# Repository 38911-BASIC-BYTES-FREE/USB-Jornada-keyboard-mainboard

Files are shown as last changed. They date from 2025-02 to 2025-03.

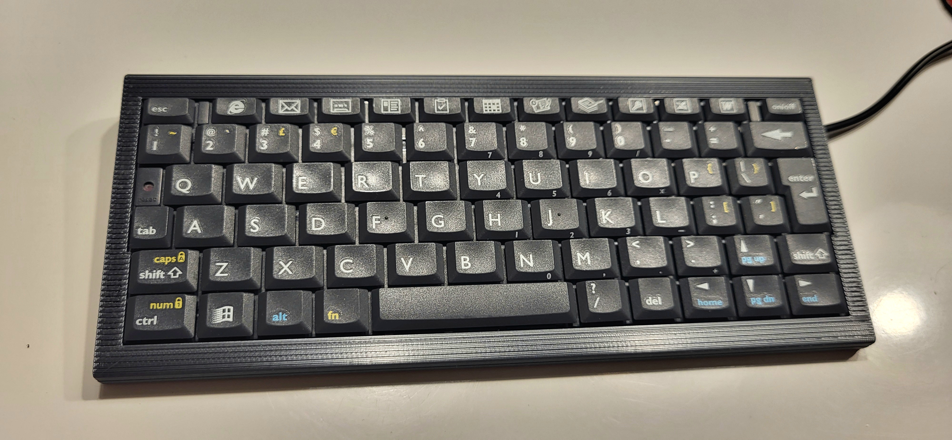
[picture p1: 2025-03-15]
Jornada-Keyboard-Code-FN-english/English_lauout_with_FN.jpg

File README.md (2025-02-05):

Jornada keyboard adapter for using it as a USB HID Keyboard.
Compile it and upload in Arduino choosing Arduino Micro board.
Modification of https://github.com/RasmusB/USB-Keyboard-Adapter .
Used in project https://www.thingiverse.com/thing:6938611 .
PCB project in the folder Jornada_keyboard_mainboard .

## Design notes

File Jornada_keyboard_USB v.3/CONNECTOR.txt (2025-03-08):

INTERFACE		KEYBOARD
CONNECTOR		CONNECTOR
  01 PB1|	----	|24	COL_13 
  02 PB2|	----	|23	COL_12
  03 PB3|	----	|22	COL_11
  04 PB0|	----	|21	COL_10
  05 PB7|	----	|20	COL_09
  06 PD0|	----	|19	COL_08
  07 PD1|	----	|18	COL_07
  08 PD2|	----	|17	COL_06
  09 PD3|	----	|16	NC
  10 PD4|	FLAT	|15	NC
  11 PD6|	FFC	|14	NC
  12 PD7|	24-PIN	|13	NC
  13 PB4|	A-A	|12	ROW_01
  14 PB5|	----	|11	ROW_02
  15 PB6|	----	|10	ROW_03
  16 PC6|	----	|09	ROW_04
  17 PC7|	----	|08	ROW_05
  18 PF7|	----	|07	ROW_06
  19 PF6|	----	|06	COL_05
  20 PF5|	----	|05	COL_04
  21 PF4|	----	|04	COL_03
  22 PF1|	----	|03	COL_02
  23 PF0|	----	|02	COL_01
  24 PE6|	----	|01	COL_00

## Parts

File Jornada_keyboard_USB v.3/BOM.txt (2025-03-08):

"Reference","Value","Datasheet","Footprint","Qty","DNP"
"C1","4.7nF","","Capacitor_SMD:C_1206_3216Metric","1",""
"C2,C3","6.2pF","","Capacitor_SMD:C_1206_3216Metric","2",""
"C4,C12","1uF","","Capacitor_SMD:C_1206_3216Metric","2",""
"C11","100nF","","Capacitor_SMD:C_1206_3216Metric","1",""
"D1","LED","~","LED_SMD:LED_1206_3216Metric","1",""
"F2","Fuse_Small","~","Fuse:Fuse_1206_3216Metric","1",""
"J1,J4,J5,J6,J7,J8","Conn_01x01_Socket","~","Connector_Wire:SolderWirePad_1x01_SMD_1x2mm","6",""
"J2","USB_B_Micro","~","Connector_USB:USB_Micro-B_Amphenol_10104110_Horizontal","1",""
"J3","Conn_01x24_MountingPin","~","Connector_FFC-FPC:TE_2-84952-4_1x24-1MP_P1.0mm_Horizontal","1",""
"R1","1M","","Resistor_SMD:R_1206_3216Metric","1",""
"R2,R3","22","","Resistor_SMD:R_1206_3216Metric","2",""
"R4,R6","10k","~","Resistor_SMD:R_1206_3216Metric","2",""
"R5","860R","~","Resistor_SMD:R_1206_3216Metric","1",""
"R7","0R","~","Resistor_SMD:R_1206_3216Metric","1",""
"SW1","SW_Omron_B3FS","https://omronfs.omron.com/en_US/ecb/products/pdf/en-b3fs.pdf","Button_Switch_SMD:SW_SPST_PTS645","1",""
"U1","ATmega32U4-A","http://ww1.microchip.com/downloads/en/DeviceDoc/Atmel-7766-8-bit-AVR-ATmega16U4-32U4_Datasheet.pdf","Package_QFP:TQFP-44_10x10mm_P0.8mm","1",""
"Y1","Crystal_GND24","~","Crystal:Crystal_SMD_3225-4Pin_3.2x2.5mm_HandSoldering","1",""

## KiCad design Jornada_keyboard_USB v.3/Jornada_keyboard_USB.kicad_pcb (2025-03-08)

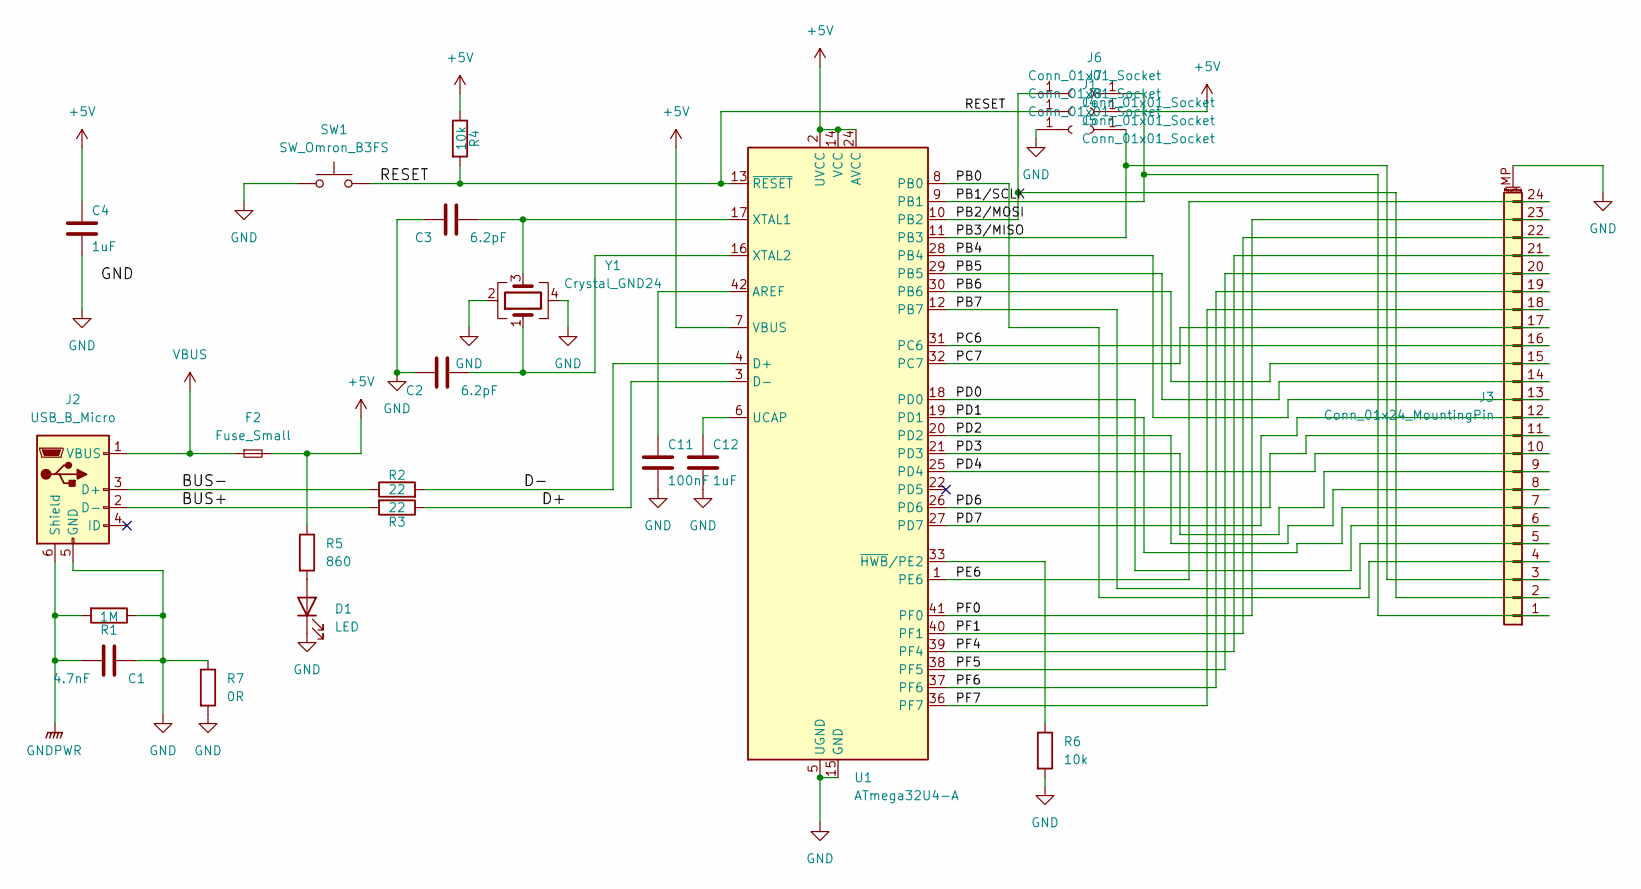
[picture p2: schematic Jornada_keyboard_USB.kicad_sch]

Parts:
C1: 4.7nF; C_1206_3216Metric; MPN 0402B472K500NT; JLCPCB C1538
C2, C3: 6.2pF; C_1206_3216Metric; MPN CC0402CRNPO9BN6R2; JLCPCB C325456
C4, C12: 1uF; C_1206_3216Metric; MPN CL05A105KA5NQNC; JLCPCB C52923
C11: 100nF; C_1206_3216Metric; MPN CL05B104KO5NNNC; JLCPCB C1525
D1: LED; LED_1206_3216Metric
F2: Fuse_Small; Fuse_1206_3216Metric
J1, J4, J5, J6, J7, J8: Conn_01x01_Socket; SolderWirePad_1x01_SMD_1x2mm
J2: USB_B_Micro; USB_Micro-B_Amphenol_10104110_Horizontal
J3: Conn_01x24_MountingPin; TE_2-84952-4_1x24-1MP_P1.0mm_Horizontal
R1: 1M; R_1206_3216Metric; MPN 0402WGF1004TCE; JLCPCB C26083
R2, R3: 22; R_1206_3216Metric; MPN 0402WGF220JTCE; JLCPCB C25092
R4: 10k; R_1206_3216Metric; MPN 0402WGF1002TCE; JLCPCB C25744
R5: 860; R_1206_3216Metric
R6: 10k; R_1206_3216Metric
R7: 0R; R_1206_3216Metric
SW1: SW_Omron_B3FS; SW_SPST_PTS645
U1: ATmega32U4-A; TQFP-44_10x10mm_P0.8mm
Y1: Crystal_GND24; Crystal_SMD_3225-4Pin_3.2x2.5mm_HandSoldering

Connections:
+5V: C4.1, F2.2, J7.1, R4.1, R5.1, U1.2 (UVCC), U1.7 (VBUS), U1.14 (VCC), U1.24 (AVCC), U1.34 (VCC), U1.44 (AVCC)
/BUS+: J2.2 (D-), R3.2
/BUS-: J2.3 (D+), R2.1
/D+: R3.1, U1.3 (D-)
/D-: R2.2, U1.4 (D+)
/PB0: J3.4, U1.8 (PB0)
/PB1/SCLK: J3.1, J6.1, U1.9 (PB1)
/PB2/MOSI: J1.1, J3.2, U1.10 (PB2)
/PB3/MISO: J3.3, J8.1, U1.11 (PB3)
/PB4: J3.13, U1.28 (PB4)
/PB5: J3.14, U1.29 (PB5)
/PB6: J3.15, U1.30 (PB6)
/PB7: J3.5, U1.12 (PB7)
/PC6: J3.16, U1.31 (PC6)
/PC7: J3.17, U1.32 (PC7)
/PD0: J3.6, U1.18 (PD0)
/PD1: J3.7, U1.19 (PD1)
/PD2: J3.8, U1.20 (PD2)
/PD3: J3.9, U1.21 (PD3)
/PD4: J3.10, U1.25 (PD4)
/PD6: J3.11, U1.26 (PD6)
/PD7: J3.12, U1.27 (PD7)
/PE6: J3.24, U1.1 (PE6)
/PF0: J3.23, U1.41 (PF0)
/PF1: J3.22, U1.40 (PF1)
/PF4: J3.21, U1.39 (PF4)
/PF5: J3.20, U1.38 (PF5)
/PF6: J3.19, U1.37 (PF6)
/PF7: J3.18, U1.36 (PF7)
/RESET: J4.1, R4.2, SW1.2, U1.13 (~RESET)
GND: C1.1, C2.2, C3.2, C4.2, C11.2, C12.2, D1.1 (K), J2.5 (GND), J3.MP (MountPin), J5.1, R1.1, R6.2, R7.1, R7.2, SW1.1, U1.5 (UGND), U1.15 (GND), U1.23 (GND), U1.35 (GND), U1.43 (GND), Y1.2, Y1.4
GNDPWR: C1.2, J2.6 (Shield), R1.2
unnamed: D1.2 (A), R5.2
unnamed: C11.1, U1.42 (AREF)
unnamed: C12.1, U1.6 (UCAP)
unnamed: C3.1, U1.17 (XTAL1), Y1.3
unnamed: C2.1, U1.16 (XTAL2), Y1.1
unnamed: R6.1, U1.33 (~HWB/PE2)
VBUS: F2.1, J2.1 (VBUS)

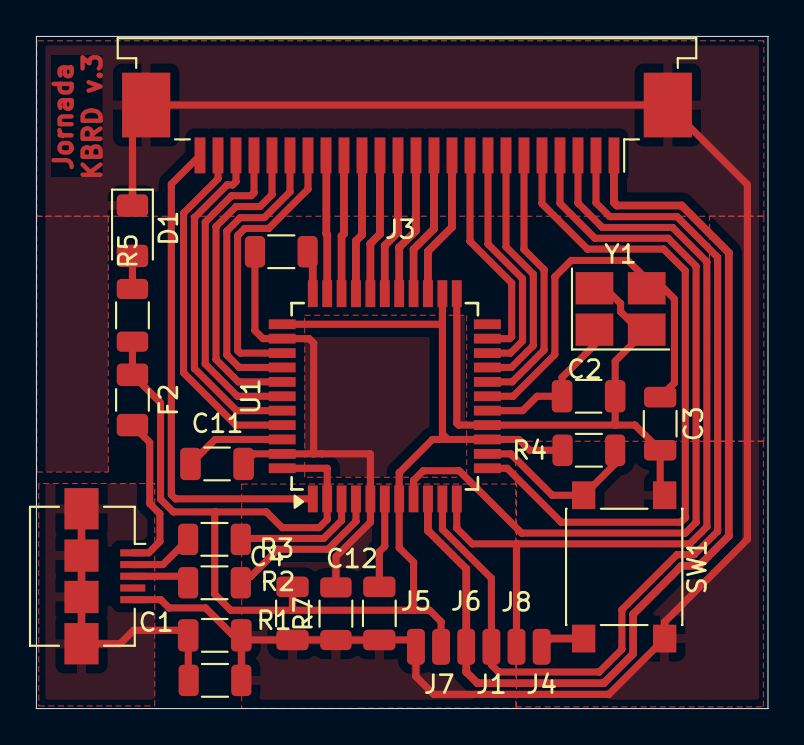
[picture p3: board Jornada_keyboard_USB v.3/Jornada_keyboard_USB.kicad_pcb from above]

Board: 2 copper layers, 40.6 x 37.3 mm, 26 parts (0 on the bottom side), 39 nets.

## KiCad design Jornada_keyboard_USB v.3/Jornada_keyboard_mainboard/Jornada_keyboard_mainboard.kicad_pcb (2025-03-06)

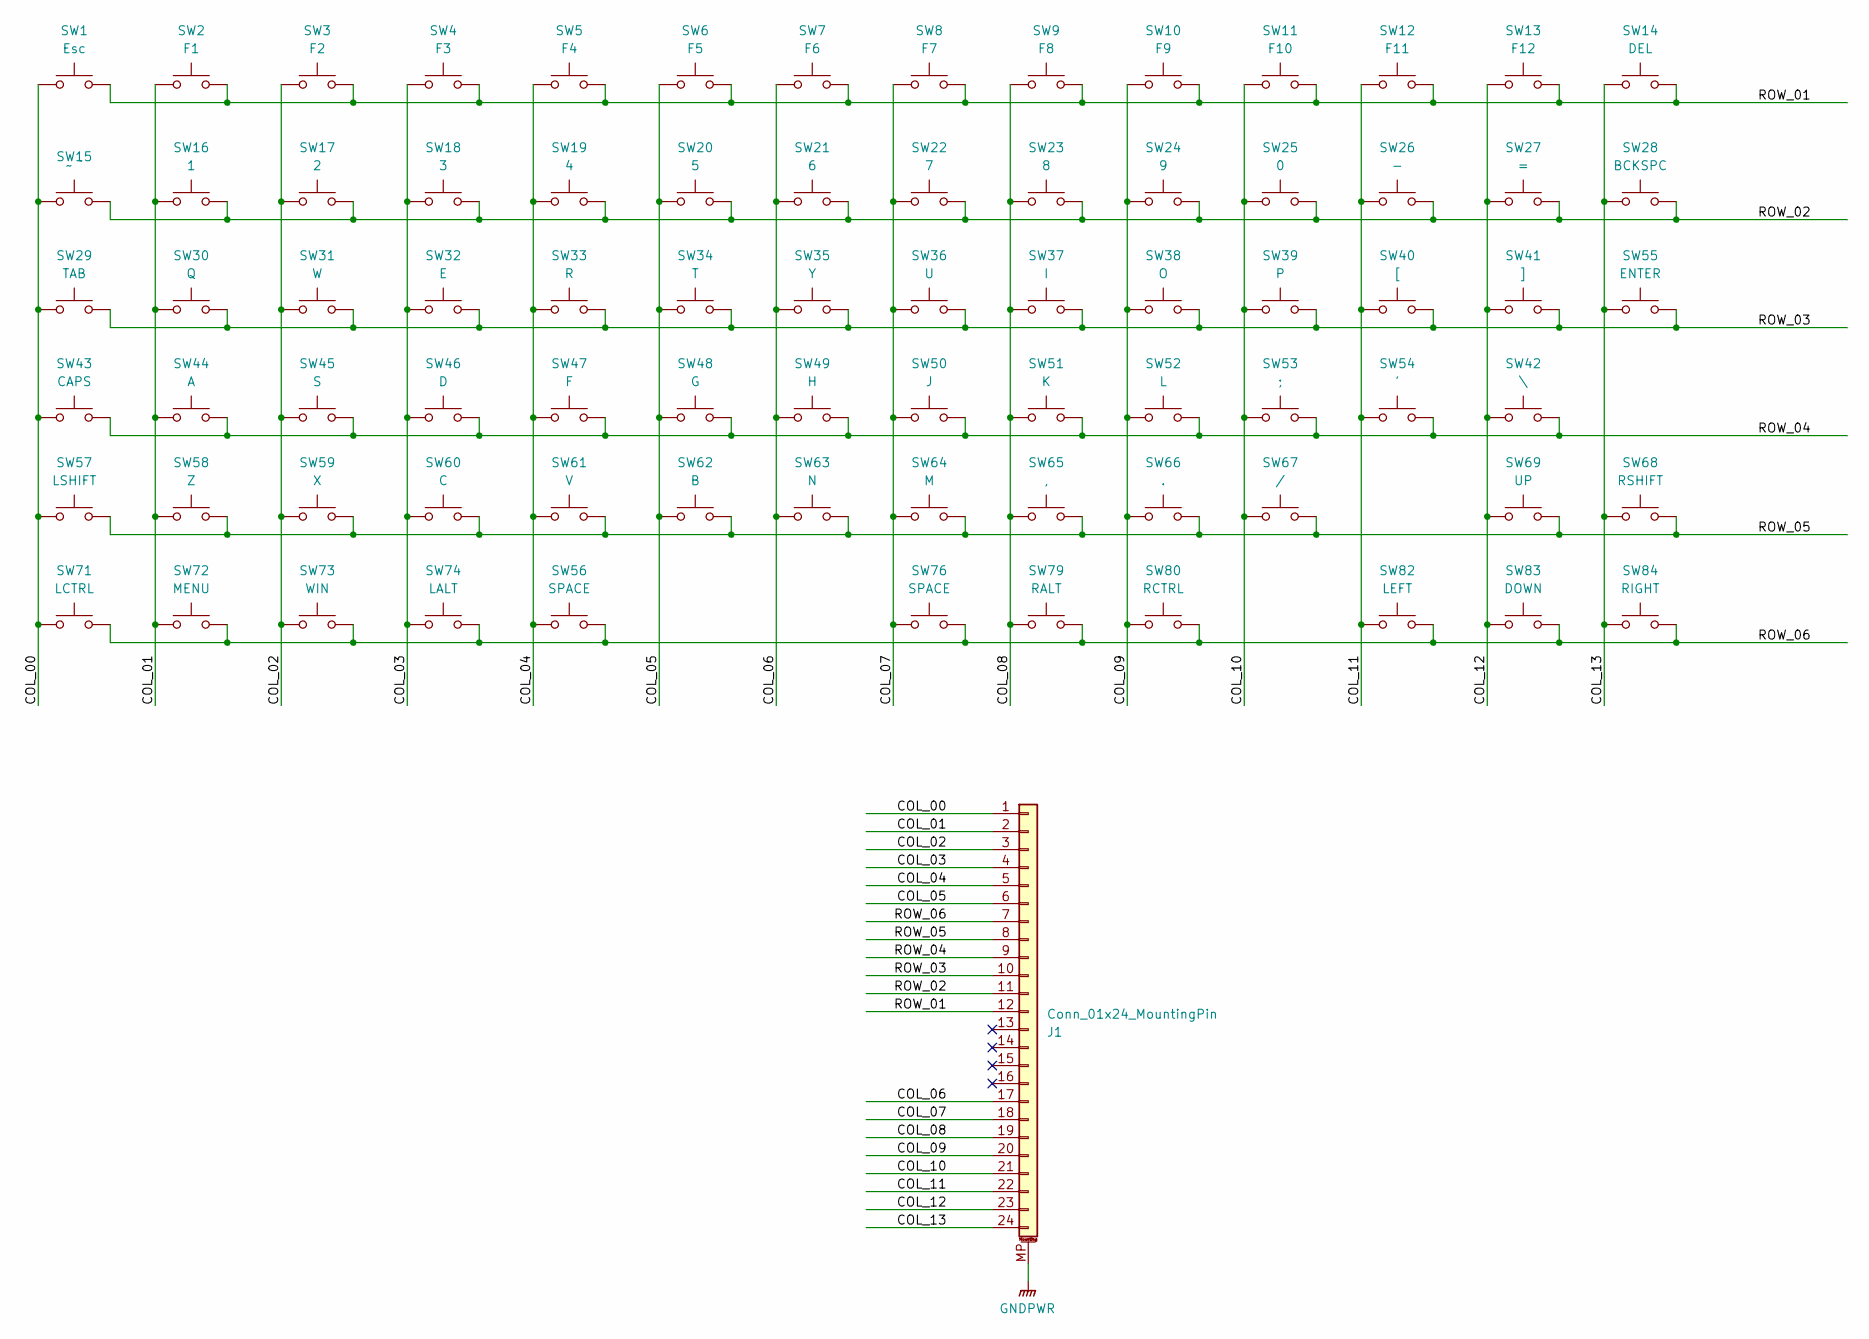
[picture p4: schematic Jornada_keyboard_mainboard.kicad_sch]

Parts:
J1: Conn_01x24_MountingPin; TE_2-84952-4_1x24-1MP_P1.0mm_Horizontal
SW1: Esc; SW_SPST_PTS647_Sx38
SW2: F1; SW_SPST_PTS647_Sx38
SW3: F2; SW_SPST_PTS647_Sx38
SW4: F3; SW_SPST_PTS647_Sx38
SW5: F4; SW_SPST_PTS647_Sx38
SW6: F5; SW_SPST_PTS647_Sx38
SW7: F6; SW_SPST_PTS647_Sx38
SW8: F7; SW_SPST_PTS647_Sx38
SW9: F8; SW_SPST_PTS647_Sx38
SW10: F9; SW_SPST_PTS647_Sx38
SW11: F10; SW_SPST_PTS647_Sx38
SW12: F11; SW_SPST_PTS647_Sx38
SW13: F12; SW_SPST_PTS647_Sx38
SW14: DEL; SW_SPST_PTS647_Sx38
SW15: ~ `; SW_SPST_PTS647_Sx38
SW16: 1; SW_SPST_PTS647_Sx38
SW17: 2; SW_SPST_PTS647_Sx38
SW18: 3; SW_SPST_PTS647_Sx38
SW19: 4; SW_SPST_PTS647_Sx38
SW20: 5; SW_SPST_PTS647_Sx38
SW21: 6; SW_SPST_PTS647_Sx38
SW22: 7; SW_SPST_PTS647_Sx38
SW23: 8; SW_SPST_PTS647_Sx38
SW24: 9; SW_SPST_PTS647_Sx38
SW25: 0; SW_SPST_PTS647_Sx38
SW26: -; SW_SPST_PTS647_Sx38
SW27: =; SW_SPST_PTS647_Sx38
SW28: BCKSPC; SW_SPST_PTS647_Sx38
SW29: TAB; SW_SPST_PTS647_Sx38
SW30: Q; SW_SPST_PTS647_Sx38
SW31: W; SW_SPST_PTS647_Sx38
SW32: E; SW_SPST_PTS647_Sx38
SW33: R; SW_SPST_PTS647_Sx38
SW34: T; SW_SPST_PTS647_Sx38
SW35: Y; SW_SPST_PTS647_Sx38
SW36: U; SW_SPST_PTS647_Sx38
SW37: I; SW_SPST_PTS647_Sx38
SW38: O; SW_SPST_PTS647_Sx38
SW39: P; SW_SPST_PTS647_Sx38
SW40: [; SW_SPST_PTS647_Sx38
SW41: ]; SW_SPST_PTS647_Sx38
SW42: \; SW_SPST_PTS647_Sx38
SW43: CAPS; SW_SPST_PTS647_Sx38
SW44: A; SW_SPST_PTS647_Sx38
SW45: S; SW_SPST_PTS647_Sx38
SW46: D; SW_SPST_PTS647_Sx38
SW47: F; SW_SPST_PTS647_Sx38
SW48: G; SW_SPST_PTS647_Sx38
SW49: H; SW_SPST_PTS647_Sx38
SW50: J; SW_SPST_PTS647_Sx38
SW51: K; SW_SPST_PTS647_Sx38
SW52: L; SW_SPST_PTS647_Sx38
SW53: ;; SW_SPST_PTS647_Sx38
SW54: '; SW_SPST_PTS647_Sx38
SW55: ENTER; SW_SPST_PTS647_Sx38
SW56, SW76: SPACE; SW_SPST_PTS647_Sx38
SW57: LSHIFT; SW_SPST_PTS647_Sx38
SW58: Z; SW_SPST_PTS647_Sx38
SW59: X; SW_SPST_PTS647_Sx38
SW60: C; SW_SPST_PTS647_Sx38
SW61: V; SW_SPST_PTS647_Sx38
SW62: B; SW_SPST_PTS647_Sx38
SW63: N; SW_SPST_PTS647_Sx38
SW64: M; SW_SPST_PTS647_Sx38
SW65: ,; SW_SPST_PTS647_Sx38
SW66: .; SW_SPST_PTS647_Sx38
SW67: /; SW_SPST_PTS647_Sx38
SW68: RSHIFT; SW_SPST_PTS647_Sx38
SW69: UP; SW_SPST_PTS647_Sx38
SW71: LCTRL; SW_SPST_PTS647_Sx38
SW72: MENU; SW_SPST_PTS647_Sx38
SW73: WIN; SW_SPST_PTS647_Sx38
SW74: LALT; SW_SPST_PTS647_Sx38
SW79: RALT; SW_SPST_PTS647_Sx38
SW80: RCTRL; SW_SPST_PTS647_Sx38
SW82: LEFT; SW_SPST_PTS647_Sx38
SW83: DOWN; SW_SPST_PTS647_Sx38
SW84: RIGHT; SW_SPST_PTS647_Sx38

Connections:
/COL_00: J1.1, SW1.1, SW15.1, SW29.1, SW43.1, SW57.1, SW71.1
/COL_01: J1.2, SW2.1, SW16.1, SW30.1, SW44.1, SW58.1, SW72.1
/COL_02: J1.3, SW3.1, SW17.1, SW31.1, SW45.1, SW59.1, SW73.1
/COL_03: J1.4, SW4.1, SW18.1, SW32.1, SW46.1, SW60.1, SW74.1
/COL_04: J1.5, SW5.1, SW19.1, SW33.1, SW47.1, SW56.1, SW61.1
/COL_05: J1.6, SW6.1, SW20.1, SW34.1, SW48.1, SW62.1
/COL_06: J1.17, SW7.1, SW21.1, SW35.1, SW49.1, SW63.1
/COL_07: J1.18, SW8.1, SW22.1, SW36.1, SW50.1, SW64.1, SW76.1
/COL_08: J1.19, SW9.1, SW23.1, SW37.1, SW51.1, SW65.1, SW79.1
/COL_09: J1.20, SW10.1, SW24.1, SW38.1, SW52.1, SW66.1, SW80.1
/COL_10: J1.21, SW11.1, SW25.1, SW39.1, SW53.1, SW67.1
/COL_11: J1.22, SW12.1, SW26.1, SW40.1, SW54.1, SW82.1
/COL_12: J1.23, SW13.1, SW27.1, SW41.1, SW42.1, SW69.1, SW83.1
/COL_13: J1.24, SW14.1, SW28.1, SW55.1, SW68.1, SW84.1
/ROW_01: J1.12, SW1.2, SW2.2, SW3.2, SW4.2, SW5.2, SW6.2, SW7.2, SW8.2, SW9.2, SW10.2, SW11.2, SW12.2, SW13.2, SW14.2
/ROW_02: J1.11, SW15.2, SW16.2, SW17.2, SW18.2, SW19.2, SW20.2, SW21.2, SW22.2, SW23.2, SW24.2, SW25.2, SW26.2, SW27.2, SW28.2
/ROW_03: J1.10, SW29.2, SW30.2, SW31.2, SW32.2, SW33.2, SW34.2, SW35.2, SW36.2, SW37.2, SW38.2, SW39.2, SW40.2, SW41.2, SW55.2
/ROW_04: J1.9, SW42.2, SW43.2, SW44.2, SW45.2, SW46.2, SW47.2, SW48.2, SW49.2, SW50.2, SW51.2, SW52.2, SW53.2, SW54.2
/ROW_05: J1.8, SW57.2, SW58.2, SW59.2, SW60.2, SW61.2, SW62.2, SW63.2, SW64.2, SW65.2, SW66.2, SW67.2, SW68.2, SW69.2
/ROW_06: J1.7, SW56.2, SW71.2, SW72.2, SW73.2, SW74.2, SW76.2, SW79.2, SW80.2, SW82.2, SW83.2, SW84.2
GNDPWR: J1.MP (MountPin)

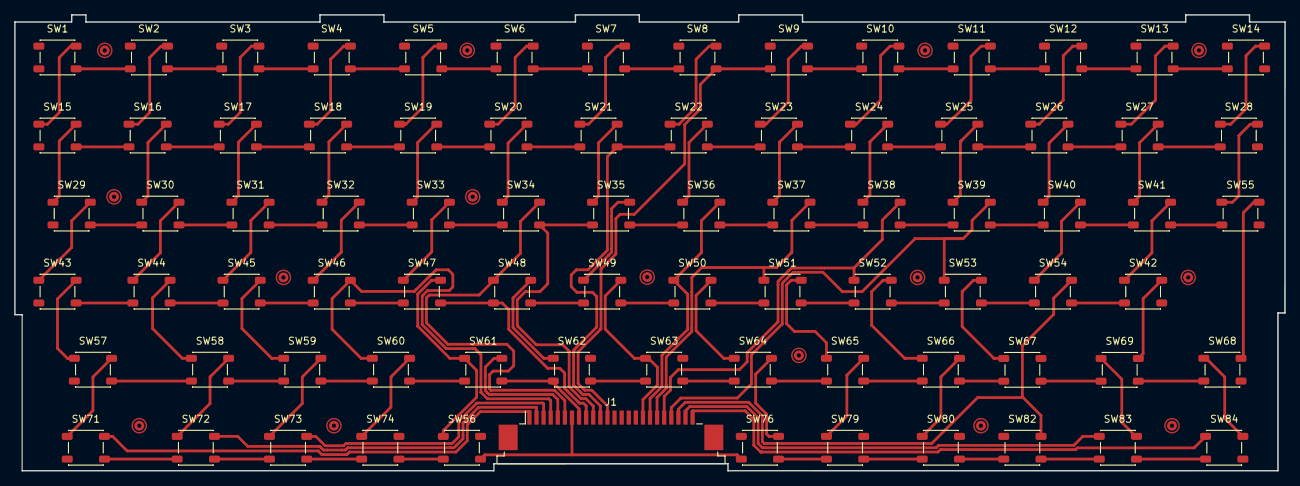
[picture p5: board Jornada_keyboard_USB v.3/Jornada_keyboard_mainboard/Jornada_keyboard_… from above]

Board: 2 copper layers, 179.0 x 64.2 mm, 80 parts (0 on the bottom side), 20 nets.

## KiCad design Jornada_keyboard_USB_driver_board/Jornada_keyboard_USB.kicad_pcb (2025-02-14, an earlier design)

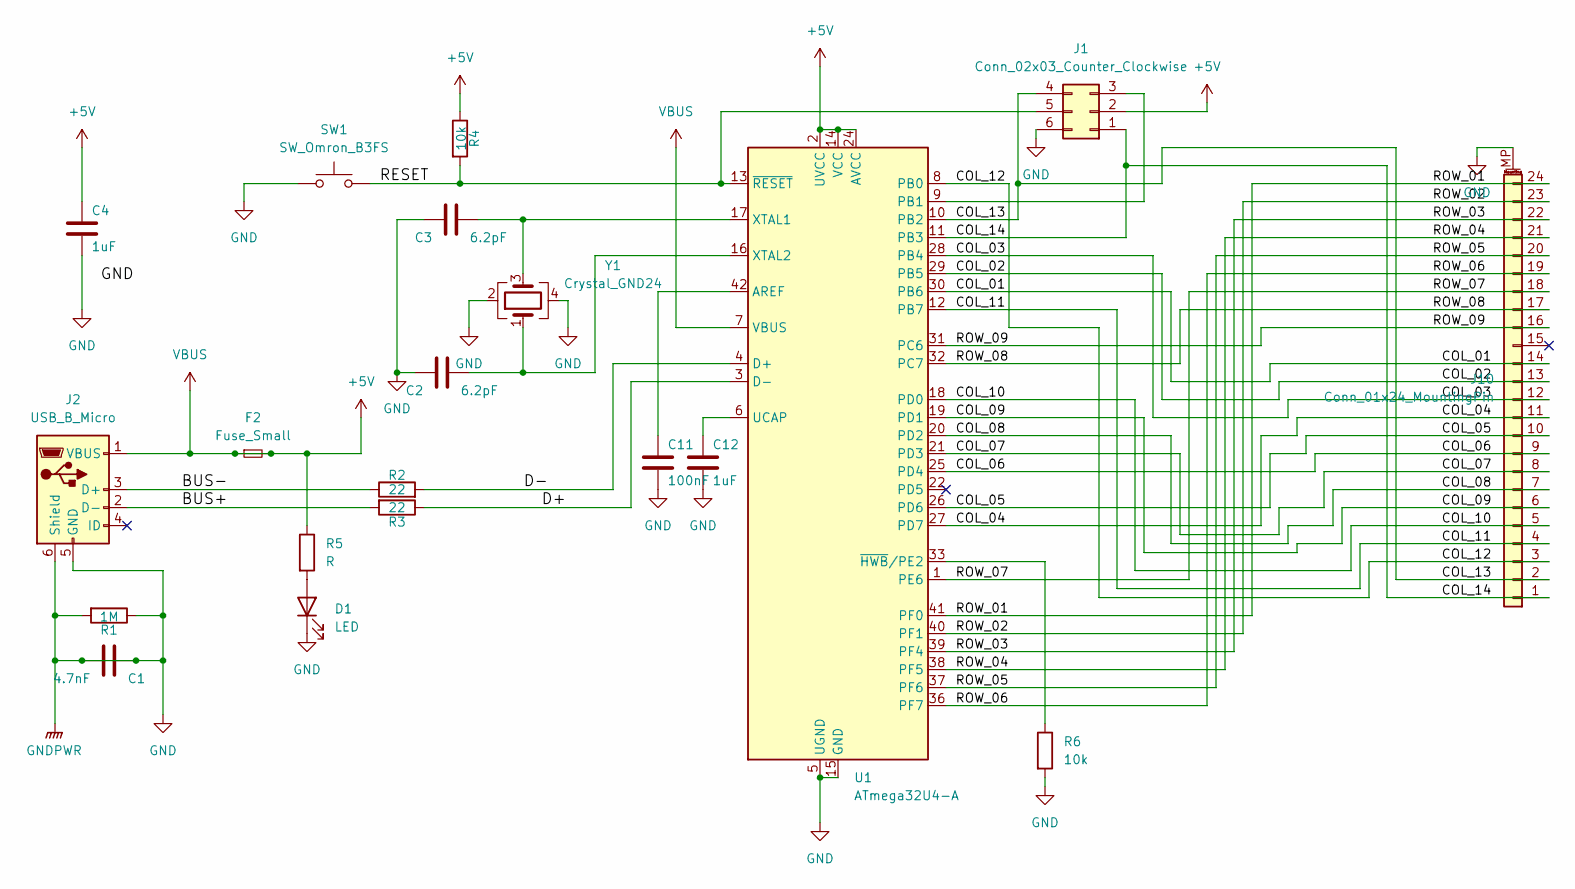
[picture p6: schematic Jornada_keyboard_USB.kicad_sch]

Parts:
C1: 4.7nF; C_1206_3216Metric; MPN 0402B472K500NT; JLCPCB C1538
C2, C3: 6.2pF; C_1206_3216Metric; MPN CC0402CRNPO9BN6R2; JLCPCB C325456
C4, C12: 1uF; C_1206_3216Metric; MPN CL05A105KA5NQNC; JLCPCB C52923
C11: 100nF; C_1206_3216Metric; MPN CL05B104KO5NNNC; JLCPCB C1525
D1: LED; LED_1206_3216Metric
F2: Fuse_Small; Fuse_1206_3216Metric
J1: Conn_02x03_Counter_Clockwise; PinHeader_2x03_P2.54mm_Vertical
J2: USB_B_Micro; USB_Micro-B_Amphenol_10104110_Horizontal
J10: Conn_01x24_MountingPin; Molex_200528-0240_1x24-1MP_P1.00mm_Horizontal
R1: 1M; R_1206_3216Metric; MPN 0402WGF1004TCE; JLCPCB C26083
R2, R3: 22; R_1206_3216Metric; MPN 0402WGF220JTCE; JLCPCB C25092
R4: 10k; R_1206_3216Metric; MPN 0402WGF1002TCE; JLCPCB C25744
R5: R; R_1206_3216Metric
R6: 10k; R_1206_3216Metric
SW1: SW_Omron_B3FS; SW_SPST_PTS645
U1: ATmega32U4-A; TQFP-44_10x10mm_P0.8mm
Y1: Crystal_GND24; Crystal_SMD_3225-4Pin_3.2x2.5mm_HandSoldering

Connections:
+5V: C4.1, F2.1, F2.2, J1.2, J2.1 (VBUS), R4.1, R5.1, U1.2 (UVCC), U1.7 (VBUS), U1.14 (VCC), U1.24 (AVCC), U1.34 (VCC), U1.44 (AVCC)
/BUS+: J2.2 (D-), R3.2
/BUS-: J2.3 (D+), R2.1
/D+: R3.1, U1.3 (D-)
/D-: R2.2, U1.4 (D+)
/RESET: J1.5, R4.2, SW1.2, U1.13 (~RESET)
GND: C1.1, C1.2, C2.2, C3.2, C4.2, C11.2, C12.2, D1.1 (K), J1.6, J2.5 (GND), J2.6 (Shield), J10.MP (MountPin), R1.1, R1.2, R6.2, SW1.1, U1.5 (UGND), U1.15 (GND), U1.23 (GND), U1.35 (GND), U1.43 (GND), Y1.2, Y1.4
unnamed: D1.2 (A), R5.2
unnamed: J1.1, J10.1, U1.11 (PB3)
unnamed: J1.3, U1.9 (PB1)
unnamed: J1.4, J10.2, U1.10 (PB2)
unnamed: J10.3, U1.8 (PB0)
unnamed: J10.4, U1.12 (PB7)
unnamed: J10.5, U1.18 (PD0)
unnamed: J10.6, U1.19 (PD1)
unnamed: J10.7, U1.20 (PD2)
unnamed: J10.8, U1.21 (PD3)
unnamed: J10.9, U1.25 (PD4)
unnamed: J10.10, U1.26 (PD6)
unnamed: J10.11, U1.27 (PD7)
unnamed: J10.12, U1.28 (PB4)
unnamed: J10.13, U1.29 (PB5)
unnamed: J10.14, U1.30 (PB6)
unnamed: J10.16, U1.31 (PC6)
unnamed: J10.17, U1.32 (PC7)
unnamed: J10.18, U1.1 (PE6)
unnamed: J10.19, U1.36 (PF7)
unnamed: J10.20, U1.37 (PF6)
unnamed: J10.21, U1.38 (PF5)
unnamed: J10.22, U1.39 (PF4)
unnamed: J10.23, U1.40 (PF1)
unnamed: J10.24, U1.41 (PF0)
unnamed: C11.1, U1.42 (AREF)
unnamed: C12.1, U1.6 (UCAP)
unnamed: C3.1, U1.17 (XTAL1), Y1.3
unnamed: C2.1, U1.16 (XTAL2), Y1.1
unnamed: R6.1, U1.33 (~HWB/PE2)

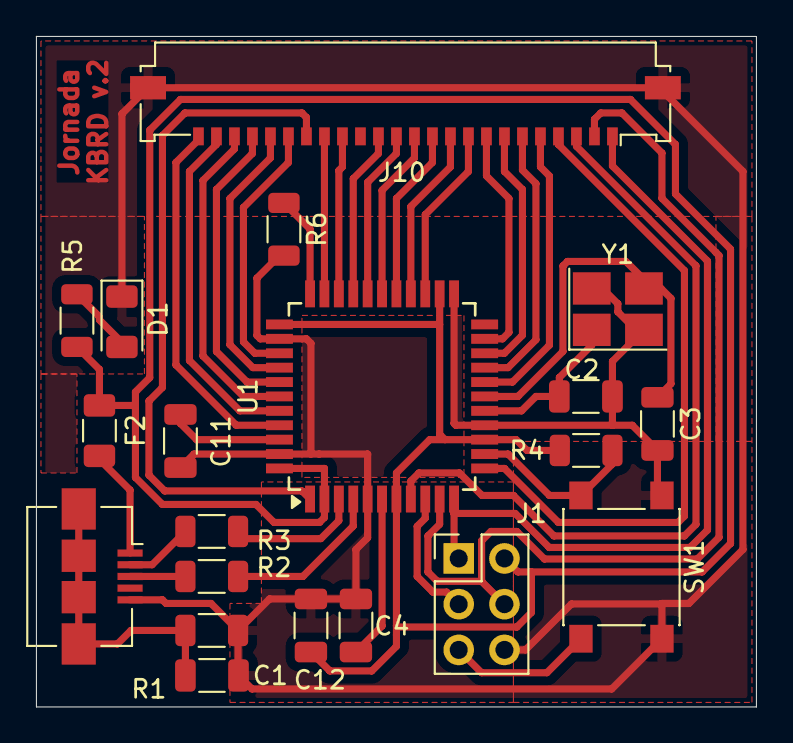
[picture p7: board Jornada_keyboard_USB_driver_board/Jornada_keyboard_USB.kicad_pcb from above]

Board: 2 copper layers, 40.0 x 37.2 mm, 20 parts (0 on the bottom side), 37 nets.

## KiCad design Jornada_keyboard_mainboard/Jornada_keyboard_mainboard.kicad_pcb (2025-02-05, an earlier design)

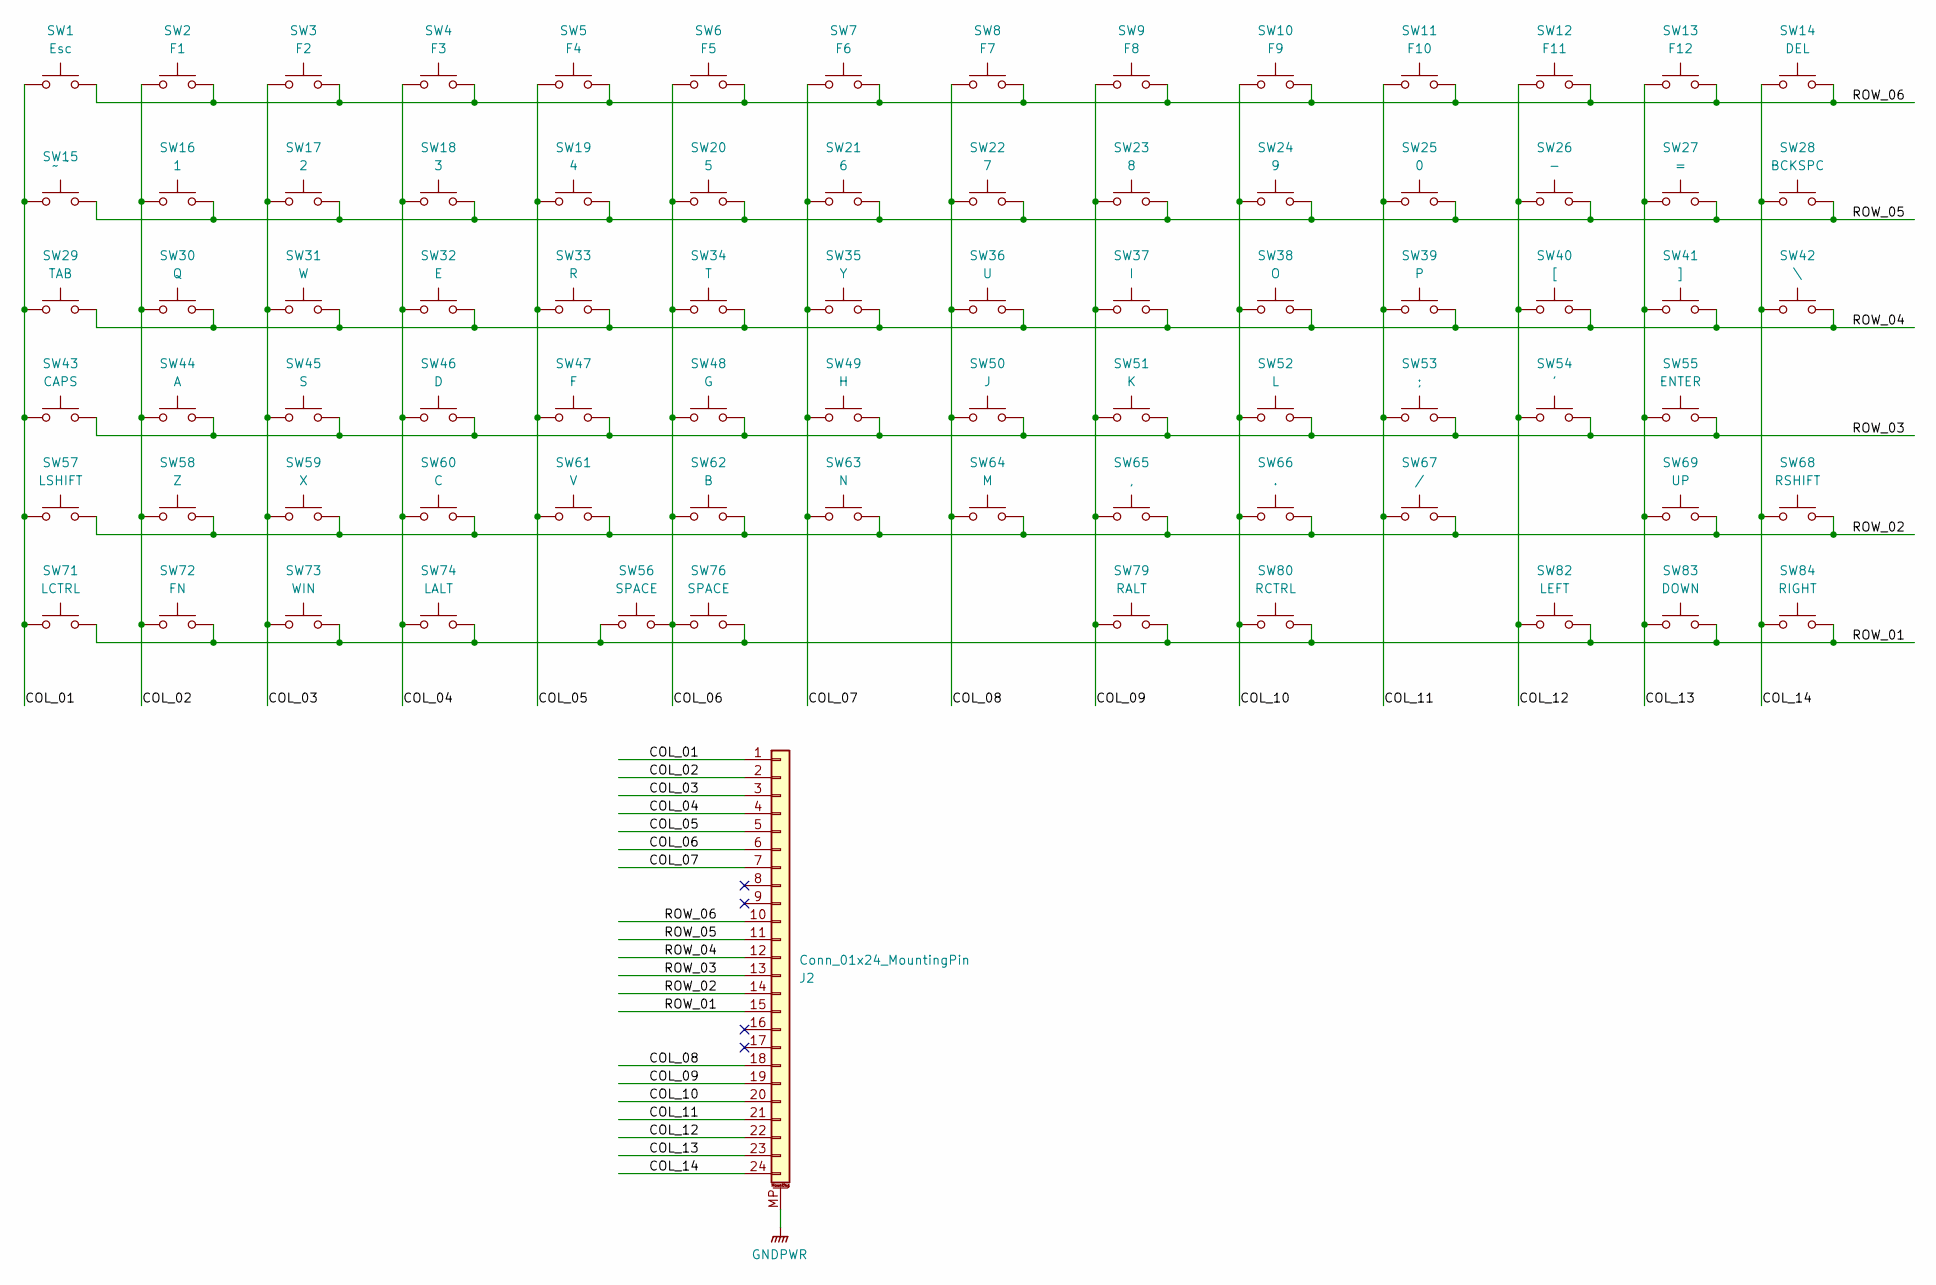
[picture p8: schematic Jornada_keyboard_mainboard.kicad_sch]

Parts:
J2: Conn_01x24_MountingPin; Molex_200528-0240_1x24-1MP_P1.00mm_Horizontal
SW1: Esc; SW_SPST_Omron_B3FS-100xP
SW2: F1; SW_SPST_Omron_B3FS-100xP
SW3: F2; SW_SPST_Omron_B3FS-100xP
SW4: F3; SW_SPST_Omron_B3FS-100xP
SW5: F4; SW_SPST_Omron_B3FS-100xP
SW6: F5; SW_SPST_Omron_B3FS-100xP
SW7: F6; SW_SPST_Omron_B3FS-100xP
SW8: F7; SW_SPST_Omron_B3FS-100xP
SW9: F8; SW_SPST_Omron_B3FS-100xP
SW10: F9; SW_SPST_Omron_B3FS-100xP
SW11: F10; SW_SPST_Omron_B3FS-100xP
SW12: F11; SW_SPST_Omron_B3FS-100xP
SW13: F12; SW_SPST_Omron_B3FS-100xP
SW14: DEL; SW_SPST_Omron_B3FS-100xP
SW15: ~ `; SW_SPST_Omron_B3FS-100xP
SW16: 1; SW_SPST_Omron_B3FS-100xP
SW17: 2; SW_SPST_Omron_B3FS-100xP
SW18: 3; SW_SPST_Omron_B3FS-100xP
SW19: 4; SW_SPST_Omron_B3FS-100xP
SW20: 5; SW_SPST_Omron_B3FS-100xP
SW21: 6; SW_SPST_Omron_B3FS-100xP
SW22: 7; SW_SPST_Omron_B3FS-100xP
SW23: 8; SW_SPST_Omron_B3FS-100xP
SW24: 9; SW_SPST_Omron_B3FS-100xP
SW25: 0; SW_SPST_Omron_B3FS-100xP
SW26: -; SW_SPST_Omron_B3FS-100xP
SW27: =; SW_SPST_Omron_B3FS-100xP
SW28: BCKSPC; SW_SPST_Omron_B3FS-100xP
SW29: TAB; SW_SPST_Omron_B3FS-100xP
SW30: Q; SW_SPST_Omron_B3FS-100xP
SW31: W; SW_SPST_Omron_B3FS-100xP
SW32: E; SW_SPST_Omron_B3FS-100xP
SW33: R; SW_SPST_Omron_B3FS-100xP
SW34: T; SW_SPST_Omron_B3FS-100xP
SW35: Y; SW_SPST_Omron_B3FS-100xP
SW36: U; SW_SPST_Omron_B3FS-100xP
SW37: I; SW_SPST_Omron_B3FS-100xP
SW38: O; SW_SPST_Omron_B3FS-100xP
SW39: P; SW_SPST_Omron_B3FS-100xP
SW40: [; SW_SPST_Omron_B3FS-100xP
SW41: ]; SW_SPST_Omron_B3FS-100xP
SW42: \; SW_SPST_Omron_B3FS-100xP
SW43: CAPS; SW_SPST_Omron_B3FS-100xP
SW44: A; SW_SPST_Omron_B3FS-100xP
SW45: S; SW_SPST_Omron_B3FS-100xP
SW46: D; SW_SPST_Omron_B3FS-100xP
SW47: F; SW_SPST_Omron_B3FS-100xP
SW48: G; SW_SPST_Omron_B3FS-100xP
SW49: H; SW_SPST_Omron_B3FS-100xP
SW50: J; SW_SPST_Omron_B3FS-100xP
SW51: K; SW_SPST_Omron_B3FS-100xP
SW52: L; SW_SPST_Omron_B3FS-100xP
SW53: ;; SW_SPST_Omron_B3FS-100xP
SW54: '; SW_SPST_Omron_B3FS-100xP
SW55: ENTER; SW_SPST_Omron_B3FS-100xP
SW56, SW76: SPACE; SW_SPST_Omron_B3FS-100xP
SW57: LSHIFT; SW_SPST_Omron_B3FS-100xP
SW58: Z; SW_SPST_Omron_B3FS-100xP
SW59: X; SW_SPST_Omron_B3FS-100xP
SW60: C; SW_SPST_Omron_B3FS-100xP
SW61: V; SW_SPST_Omron_B3FS-100xP
SW62: B; SW_SPST_Omron_B3FS-100xP
SW63: N; SW_SPST_Omron_B3FS-100xP
SW64: M; SW_SPST_Omron_B3FS-100xP
SW65: ,; SW_SPST_Omron_B3FS-100xP
SW66: .; SW_SPST_Omron_B3FS-100xP
SW67: /; SW_SPST_Omron_B3FS-100xP
SW68: RSHIFT; SW_SPST_Omron_B3FS-100xP
SW69: UP; SW_SPST_Omron_B3FS-100xP
SW71: LCTRL; SW_SPST_Omron_B3FS-100xP
SW72: FN; SW_SPST_Omron_B3FS-100xP
SW73: WIN; SW_SPST_Omron_B3FS-100xP
SW74: LALT; SW_SPST_Omron_B3FS-100xP
SW79: RALT; SW_SPST_Omron_B3FS-100xP
SW80: RCTRL; SW_SPST_Omron_B3FS-100xP
SW82: LEFT; SW_SPST_Omron_B3FS-100xP
SW83: DOWN; SW_SPST_Omron_B3FS-100xP
SW84: RIGHT; SW_SPST_Omron_B3FS-100xP

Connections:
/COL_01: J2.1, SW1.1, SW15.1, SW29.1, SW43.1, SW57.1, SW71.1
/COL_02: J2.2, SW2.1, SW16.1, SW30.1, SW44.1, SW58.1, SW72.1
/COL_03: J2.3, SW3.1, SW17.1, SW31.1, SW45.1, SW59.1, SW73.1
/COL_04: J2.4, SW4.1, SW18.1, SW32.1, SW46.1, SW60.1, SW74.1
/COL_05: J2.5, SW5.1, SW19.1, SW33.1, SW47.1, SW61.1
/COL_06: J2.6, SW6.1, SW20.1, SW34.1, SW48.1, SW56.2, SW62.1, SW76.1
/COL_07: J2.7, SW7.1, SW21.1, SW35.1, SW49.1, SW63.1
/COL_08: J2.18, SW8.1, SW22.1, SW36.1, SW50.1, SW64.1
/COL_09: J2.19, SW9.1, SW23.1, SW37.1, SW51.1, SW65.1, SW79.1
/COL_10: J2.20, SW10.1, SW24.1, SW38.1, SW52.1, SW66.1, SW80.1
/COL_11: J2.21, SW11.1, SW25.1, SW39.1, SW53.1, SW67.1
/COL_12: J2.22, SW12.1, SW26.1, SW40.1, SW54.1, SW82.1
/COL_13: J2.23, SW13.1, SW27.1, SW41.1, SW55.1, SW69.1, SW83.1
/COL_14: J2.24, SW14.1, SW28.1, SW42.1, SW68.1, SW84.1
/ROW_01: J2.15, SW56.1, SW71.2, SW72.2, SW73.2, SW74.2, SW76.2, SW79.2, SW80.2, SW82.2, SW83.2, SW84.2
/ROW_02: J2.14, SW57.2, SW58.2, SW59.2, SW60.2, SW61.2, SW62.2, SW63.2, SW64.2, SW65.2, SW66.2, SW67.2, SW68.2, SW69.2
/ROW_03: J2.13, SW43.2, SW44.2, SW45.2, SW46.2, SW47.2, SW48.2, SW49.2, SW50.2, SW51.2, SW52.2, SW53.2, SW54.2, SW55.2
/ROW_04: J2.12, SW29.2, SW30.2, SW31.2, SW32.2, SW33.2, SW34.2, SW35.2, SW36.2, SW37.2, SW38.2, SW39.2, SW40.2, SW41.2, SW42.2
/ROW_05: J2.11, SW15.2, SW16.2, SW17.2, SW18.2, SW19.2, SW20.2, SW21.2, SW22.2, SW23.2, SW24.2, SW25.2, SW26.2, SW27.2, SW28.2
/ROW_06: J2.10, SW1.2, SW2.2, SW3.2, SW4.2, SW5.2, SW6.2, SW7.2, SW8.2, SW9.2, SW10.2, SW11.2, SW12.2, SW13.2, SW14.2
GNDPWR: J2.MP (MountPin)

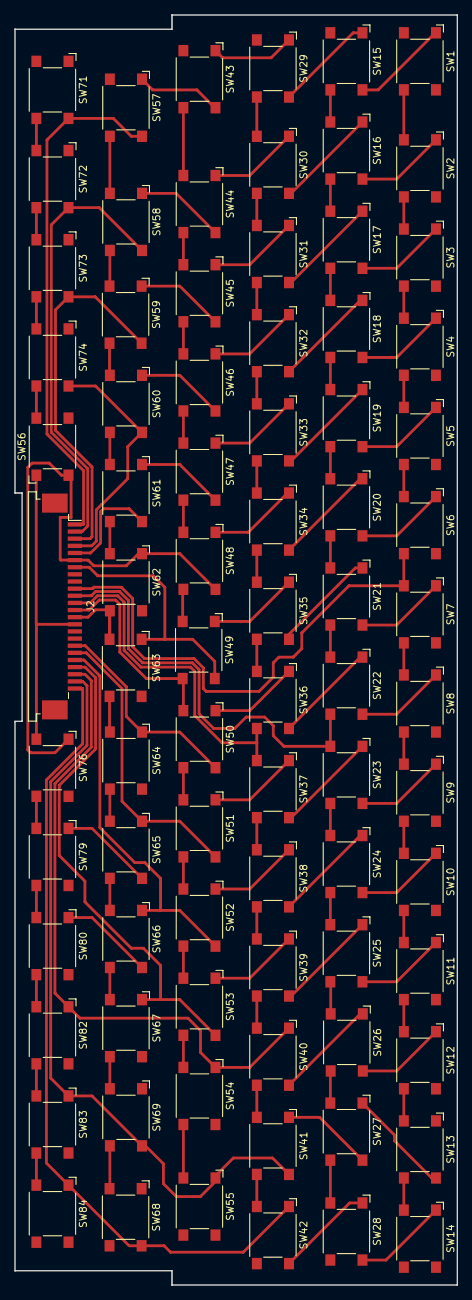
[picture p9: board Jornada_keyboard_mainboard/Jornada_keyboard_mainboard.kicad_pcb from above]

Board: 2 copper layers, 62.0 x 178.0 mm, 80 parts (0 on the bottom side), 20 nets.

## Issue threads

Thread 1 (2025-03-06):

v.3 Of Jornada_keyboard_USB_driver_board

tjcomserv, 2025-03-06:
Hello,

Thank you so much for sharing everthing you have for the build.

However, I am looking to build one of these and hoping you would supply the v.3 keyboard driver board and a list of components that are on it please?

38911-BASIC-BYTES-FREE, 2025-03-15:
Uploaded v.3 PCB and two versions of the code for it.

Closed 2025-03-15.

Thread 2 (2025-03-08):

BOM is empty

hzykiss, 2025-03-08:
Hi. Bro
     Thanks for contributing, but file A is empty, can you add one? In addition, I have tried to export the BOM using the schematic, but some components, such as the R5 resistance, seem to be missing

38911-BASIC-BYTES-FREE, 2025-03-08:
Hi.
Should be good now. R5 is 860 Ohm.
BOM and Connector were empty, indeed.

Closed 2025-03-15.

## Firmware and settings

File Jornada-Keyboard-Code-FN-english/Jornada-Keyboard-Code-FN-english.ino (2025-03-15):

/*
  Jornada-Keyboard-Code-FN
  This code doesn't handle ALT + arrows for PG_UP, PG_DOWN, HOME, END
  Use FN + arrows to have it working
  Also Pound and Euro characters are not working - they are beyond the ASCII table
  To send ~ press FN+1 and then space as it always works this way

  This is only a modification of:
  See https://github.com/RasmusB/USB-Keyboard-Adapter


*/

#include "board.h"
#include "Keyboard.h"
#include "JornadaKeymapUSB.h"

#define KEYBOARD_ENABLED true

// Max number of scans/second
#define MAX_SCAN_RATE 1000

int keypressArrayCurrent [NROWS] [NCOLS];
int keypressArrayPrevious [NROWS] [NCOLS];

unsigned long previousTime;
unsigned int minDelay;

void setup() {

  previousTime = 0;
  minDelay = 1000 / MAX_SCAN_RATE;


  if (KEYBOARD_ENABLED) Keyboard.begin();

  pinMode(LED_BUILTIN, OUTPUT);

  // Scanlines in high-Z (inactive) mode
  // Pin state should be initialized to LOW
  for (int i = 0; i < NROWS; i++) {
    pinMode(Rows[i], INPUT);
  }

  // Columns as inputs
  // Internal pull-up enabled
  for (int i = 0; i < NCOLS; i++) {
    pinMode(Cols[i], INPUT);
  }
}

void loop() {

  if ( (millis() - previousTime) >= minDelay ) {

    // Scan the keyboard matrix
    int nKeysPressed = scanKeyboard(keypressArrayCurrent);

    //digitalWrite(LED_BUILTIN, keypressArrayCurrent[7][7]);


    // Send the keypresses over USB
    if (KEYBOARD_ENABLED) {
      sendKeys(keypressArrayCurrent, keypressArrayPrevious);
    }

    // Remember which keys were pressed so we can release them later
    memcpy(keypressArrayPrevious, keypressArrayCurrent, sizeof(keypressArrayCurrent));

    previousTime = millis();
  }
}

int scanKeyboard ( int keyArray [] [NCOLS] ) {

  int nKeysPressed = 0;

  for (int row = 0; row < NROWS; row++) {


    // Select a pin to sink current
    pinMode(Rows[row], OUTPUT);
    digitalWrite(Rows[row], LOW);

    for (int col = 0; col < NCOLS; col++) {
      pinMode(Cols[col], INPUT_PULLUP);


      // Only scan mapped buttons
      if (keyScancode[row][col] != 0) {

        // =1 for every button NOT pressed (pull-ups enabled)
        // =0 for every button PRESSED (signal shorted to row pin)
        // This value is inverted when saved

        if ( digitalRead(Cols[col]) != HIGH ) {
          keyArray [row] [col] = 1;
          nKeysPressed++;

        } else {
          keyArray [row] [col] = 0;
        }
      }
      
      // Disable pull-up
      pinMode(Cols[col], INPUT);
      
    }

    // Return pin to high-Z (inactive) mode

    pinMode(Rows[row], INPUT);

  }

  return nKeysPressed;
}

void sendKeys ( int pressedArray [] [NCOLS], int previousArray [] [NCOLS] ) {

  for ( int row = 0; row < NROWS; row++ ) {
    for ( int col = 0; col < NCOLS; col++ ) {
      // Only scan mapped buttons
      if (keyScancode[row][col] != 0) {
        // If a new button is pressed
        if ( pressedArray[row][col] > previousArray[row][col] ) {
          // If FN button is pressed send codes from keyScancodeFN table but not FN itself
          if ( pressedArray[4][8] > 0 ) {
            Keyboard.press(keyScancodeFN[row][col]);
          }
          else {
            // "Normal" keypress, just send as is
            Keyboard.press(keyScancode[row][col]);
          }
          // This handles the release of keys
        } 
        else if ( pressedArray[row][col] < previousArray[row][col] ) {
          {
            Keyboard.release(keyScancode[row][col]);
            Keyboard.release(keyScancodeFN[row][col]);
          }
        }
      }
    }
  }
}

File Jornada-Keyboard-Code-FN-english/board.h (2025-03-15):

/*
 board.h
 
 This is how the pins are connected to the keyboard
 
 */



// Standard LED is moved to pin 13 and disabled
#undef LED_BUILTIN
#define LED_BUILTIN 0
 
// See the keyboard schematic for row/col mapping
#define NROWS 9
#define NCOLS 14

#define ROW_01   7 //PE6 
#define ROW_02   A5 //PF0
#define ROW_03   A4 //PF1
#define ROW_04   A3 //PF4
#define ROW_05   A2 //PF5
#define ROW_06   A1 //PF6
#define ROW_07   A0 //PF7
#define ROW_08   13 //PC7
#define ROW_09   5 //PC6

#define COL_1    9 //PB5
#define COL_2    8 //PB4
#define COL_3    6 //PD7 
#define COL_4    12 //PD6
#define COL_5    4 //PD4
#define COL_6    1 //PD3
#define COL_7    0 //PD2
#define COL_8    2 //PD1
#define COL_9    3 //PD0
#define COL_10   11 //PB7 
#define COL_11   SS //PB0
#define COL_12   MISO // PB3
#define COL_13   MOSI // PB2
#define COL_14   SCK //PB1

int Rows [NROWS] = {
  ROW_01,
  ROW_02,
  ROW_03,
  ROW_04,
  ROW_05,
  ROW_06,
  ROW_07,
  ROW_08,
  ROW_09
};

int Cols [NCOLS] = {
  COL_1,
  COL_2,
  COL_3,
  COL_4,
  COL_5,
  COL_6,
  COL_7,
  COL_8,
  COL_9,
  COL_10,
  COL_11,
  COL_12,
  COL_13,
  COL_14
};
